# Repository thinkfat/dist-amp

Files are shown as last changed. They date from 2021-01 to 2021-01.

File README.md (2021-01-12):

dist-amp
========

This repository contains a 10MHz Distribution Amplifier (4  channels). It's
use is mainly in electronics labs or ham radio shacks for distributing a 
10MHz frequency standard (GPSDO, Rb atomic clock).

The circuit is based on a design by W. H. Rech, DF9IC, with minor modifications
by myself.

Documenation
------------

The *doc* folder contains the schematic in PDF format. It also contains S11/S21 measurements
done with a NanoVNA V2plus4 (nanovna-saver screenshot):

- Maximum input: 10dBm into 50 Ohm
- Cut-off frequency (-3dB): 13.8MHz
- Roll-off: 38dB/octave
- S11 @ 10MHz: -27dB
- S21 @ 10MHz: -0.7dB

Switching the ports I got also:
- S12 @ 10MHz: < -90dB

  In other words, the VNA cannot measure it. The dynamic range is not big enough.

Fabrication
-----------

The *fab* folder contains Gerber plots, a drill file and CPL+BOM files for
JLCPCB SMT service. If you want to recreate the board, remember to enable
impedance control and choose the JLC7628 PCB stack-up.

BOM
---

The *bom* folder contains an interactive HTML BOM you can open in a browser. It will
help with sourcing parts and assembling the PCB. Most parts are generic, but some parts
must meet either footprint or electrical constraints.

- L1, L2: Johanson Technology L-15F1R0JV4E
- U2: Maxim MAX4022ESD+
- J6: CUI PJ-037BH
- C13-C15: use MLCC capacitors with C0G/NP0 dielectric

Customization
-------------

The MAX4022ESD+ has a much larger bandwidth than the 12MHz imposed by the input filter.
One obvious modification is therefore to choose a higher roll-off frequency for the
input low-pass. Note that total bandwidth and flatness will also depend on parameters
of other components in the signal path, notably coupling capacitors at in and output.
These are currently generic 100nF MLCC with X7R dielectric. For more demanding applications,
you might need to find better ones.

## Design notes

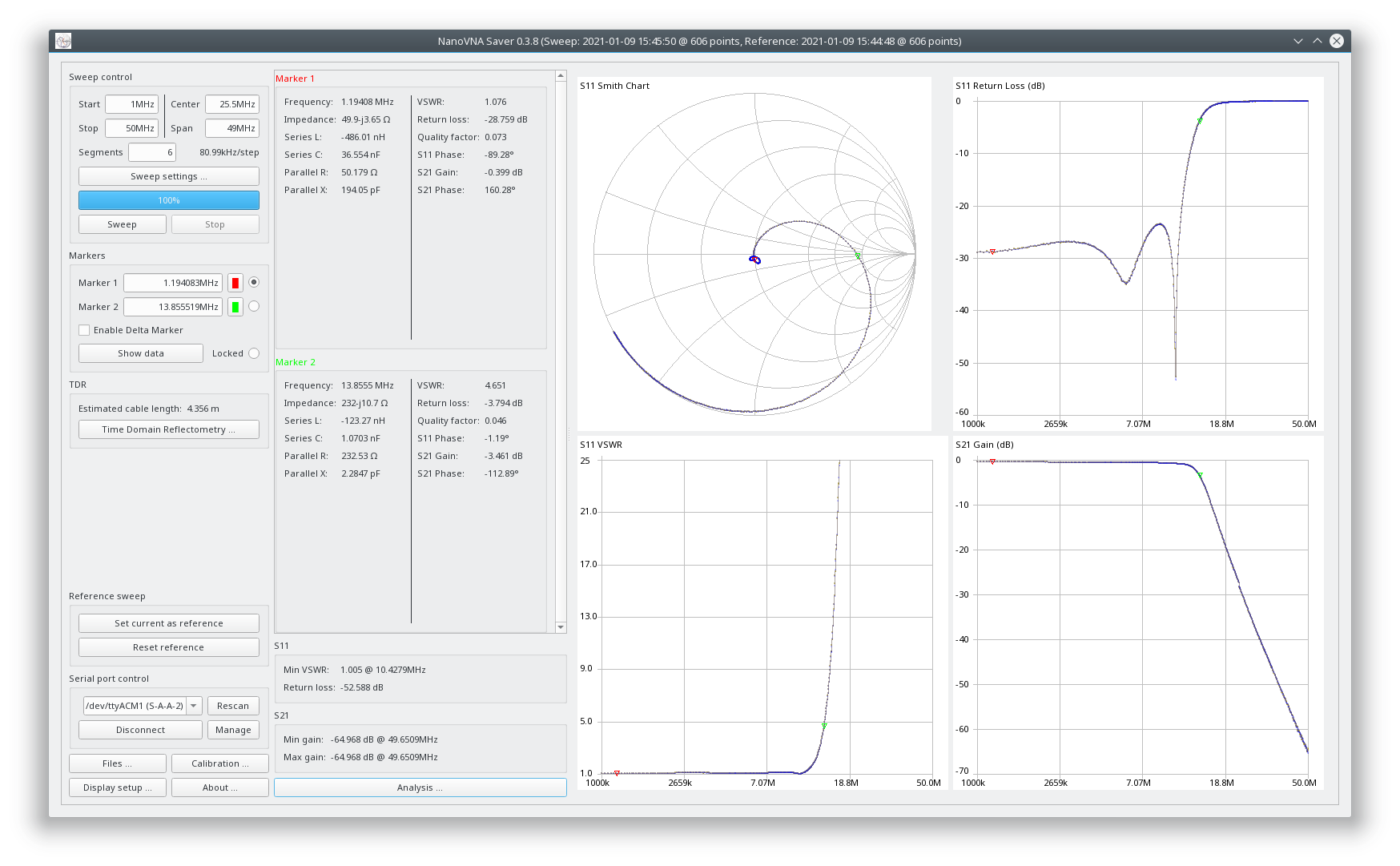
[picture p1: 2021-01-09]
doc/analysis.png

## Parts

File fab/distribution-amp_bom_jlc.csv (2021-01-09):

Comment | Designator | Footprint | LCSC Part #
10u | C8,C2,C3 | CP_Elec_5x5.4 | C72487
100n | C11,C6,C7,C10,C16,C4,C1,C9,C12,C5 | C_0805_2012Metric_Pad1.18x1.45mm_HandSolder | C49678
220p | C13,C15 | C_0805_2012Metric_Pad1.18x1.45mm_HandSolder | C61747
470p | C14 | C_0805_2012Metric_Pad1.18x1.45mm_HandSolder | C28256
1N4148WS | D1 | D_SOD-323 | C2128
49.9 | R1,R3,R5,R9,R7,R6 | R_0805_2012Metric_Pad1.20x1.40mm_HandSolder | C17720
10k | R4,R2 | R_0805_2012Metric_Pad1.20x1.40mm_HandSolder | C17414
4k7 | R8 | R_0805_2012Metric_Pad1.20x1.40mm_HandSolder | C17673
MC78M09_TO252 | U1 | TO-252-2 | C148310

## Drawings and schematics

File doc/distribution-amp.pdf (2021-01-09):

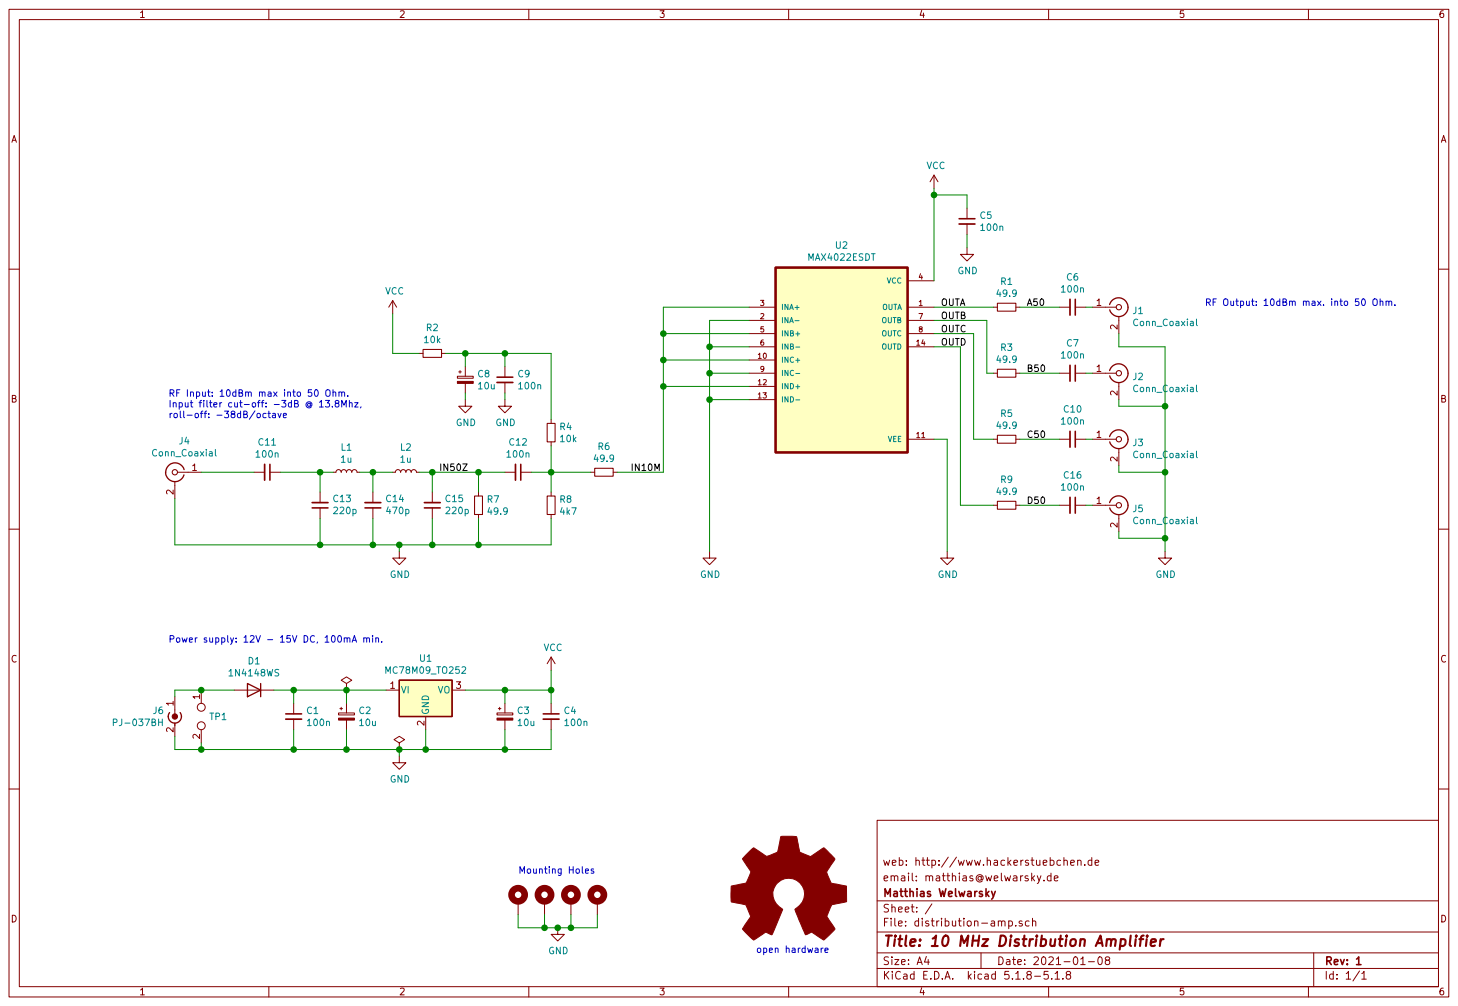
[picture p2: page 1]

INB- 6

INC- 9

RF Input: 10dBm max into 50 Ohm.

web: http://www.hackerstuebchen.de R4

IN50Z Power supply: 12V - 15V DC, 100mA min.

email: matthias@welwarsky.de
File: distribution-amp.sch Sheet: / Matthias Welwarsky

Id: 1/1 Title: 10 MHz Distribution Amplifier

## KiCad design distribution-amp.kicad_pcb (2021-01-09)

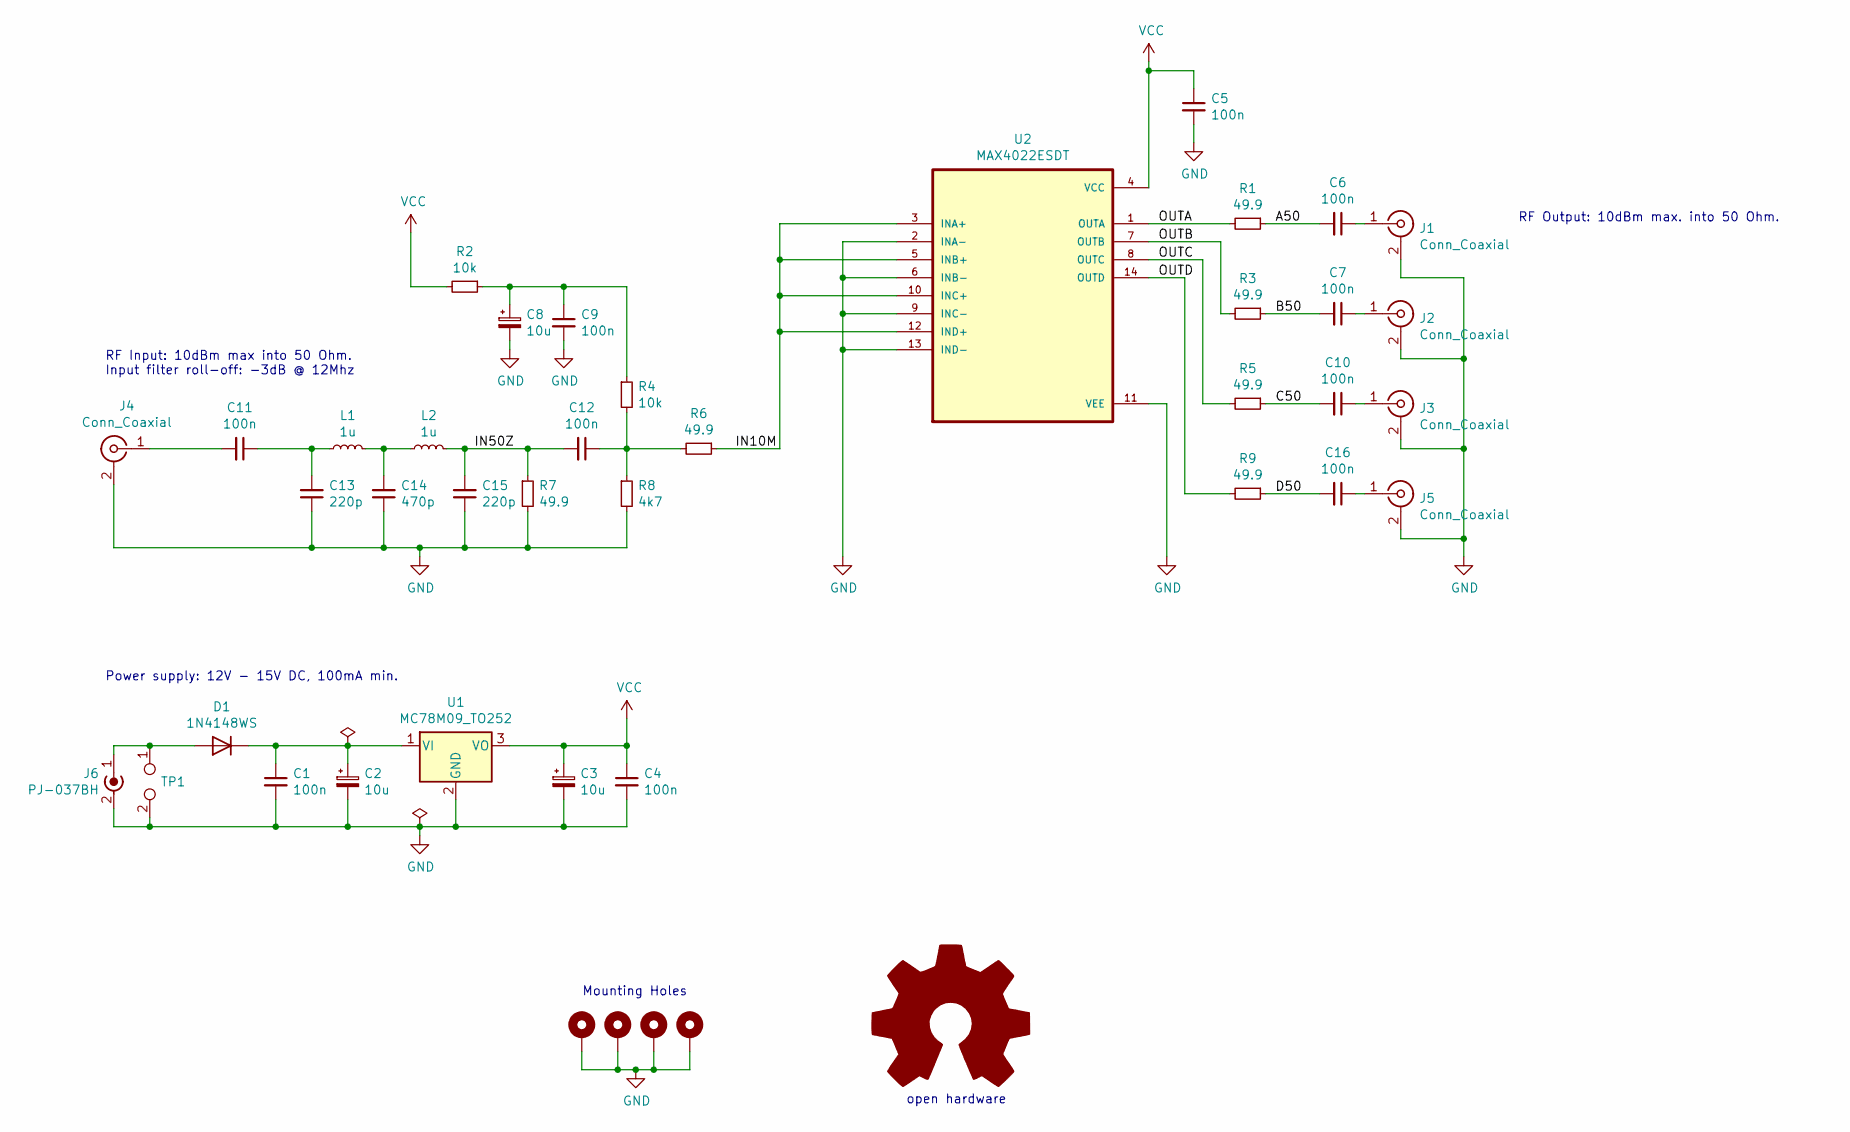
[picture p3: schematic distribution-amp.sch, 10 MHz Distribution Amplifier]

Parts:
C1, C4, C5, C6, C7, C9, C10, C11, C12, C16: 100n; C_0805_2012Metric_Pad1.18x1.45mm_HandSolder; LCSCPN C49678
C2, C3, C8: 10u; CP_Elec_5x5.4; LCSCPN C72487
C13, C15: 220p; C_0805_2012Metric_Pad1.18x1.45mm_HandSolder; LCSCPN C61747
C14: 470p; C_0805_2012Metric_Pad1.18x1.45mm_HandSolder; LCSCPN C28256
D1: 1N4148WS; D_SOD-323; LCSCPN C2128
H1, H2, H3, H4: MountingHole_Pad; MountingHole_3.2mm_M3_Pad_Via
J1, J2, J3, J4, J5: Conn_Coaxial; SMA_Amphenol_132203-12_Horizontal
J6: PJ-037BH; CUI_PJ-037BH
L1, L2: 1u; L_0805_2012Metric_Pad1.05x1.20mm_HandSolder
OSHW1: Logo_Open_Hardware_Large; OSHW-Logo2_14.6x12mm_Copper
R1, R3, R5, R6, R7, R9: 49.9; R_0805_2012Metric_Pad1.20x1.40mm_HandSolder; LCSCPN C17720
R2, R4: 10k; R_0805_2012Metric_Pad1.20x1.40mm_HandSolder; LCSCPN C17414
R8: 4k7; R_0805_2012Metric_Pad1.20x1.40mm_HandSolder; LCSCPN C17673
TP1: TestPoint_2Pole; PinHeader_1x02_P2.54mm_Vertical
U1: MC78M09_TO252; TO-252-2; LCSCPN C148310
U2: MAX4022ESDT; SOIC-14_3.9x8.7mm_P1.27mm

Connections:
/A50: C6.2, R1.1
/B50: C7.2, R3.1
/C50: C10.2, R5.1
/D50: C16.2, R9.1
/IN10M: R6.1, U2.3 (INA+), U2.5 (INB+), U2.10 (INC+), U2.12 (IND+)
/IN50Z: C12.2, C15.2, L2.2, R7.1
/OUTA: R1.2, U2.1 (OUTA)
/OUTB: R3.2, U2.7 (OUTB)
/OUTC: R5.2, U2.8 (OUTC)
/OUTD: R9.2, U2.14 (OUTD)
GND: C1.2, C2.2, C3.2, C4.2, C5.2, C8.2, C9.2, C13.1, C14.1, C15.1, H1.1, H2.1, H3.1, H4.1, J1.2 (Ext), J2.2 (Ext), J3.2 (Ext), J4.2 (Ext), J5.2 (Ext), J6.2 (Ext), R7.2, R8.2, TP1.2, U1.2 (GND), U2.2 (INA-), U2.6 (INB-), U2.9 (INC-), U2.11 (VEE), U2.13 (IND-)
unnamed: C1.1, C2.1, D1.1 (K), U1.1 (VI)
unnamed: C6.1, J1.1 (In)
unnamed: C7.1, J2.1 (In)
unnamed: C8.1, C9.1, R2.1, R4.1
unnamed: C10.1, J3.1 (In)
unnamed: C11.1, C13.2, L1.1
unnamed: C11.2, J4.1 (In)
unnamed: C12.1, R4.2, R6.2, R8.1
unnamed: C14.2, L1.2, L2.1
unnamed: C16.1, J5.1 (In)
unnamed: D1.2 (A), J6.1 (In), TP1.1
VCC: C3.1, C4.1, C5.1, R2.2, U1.3 (VO), U2.4 (VCC)

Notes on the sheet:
open hardware
Mounting Holes
Power supply: 12V - 15V DC, 100mA min.
RF Input: 10dBm max into 50 Ohm. Input filter roll-off: -3dB @ 12Mhz
RF Output: 10dBm max. into 50 Ohm.

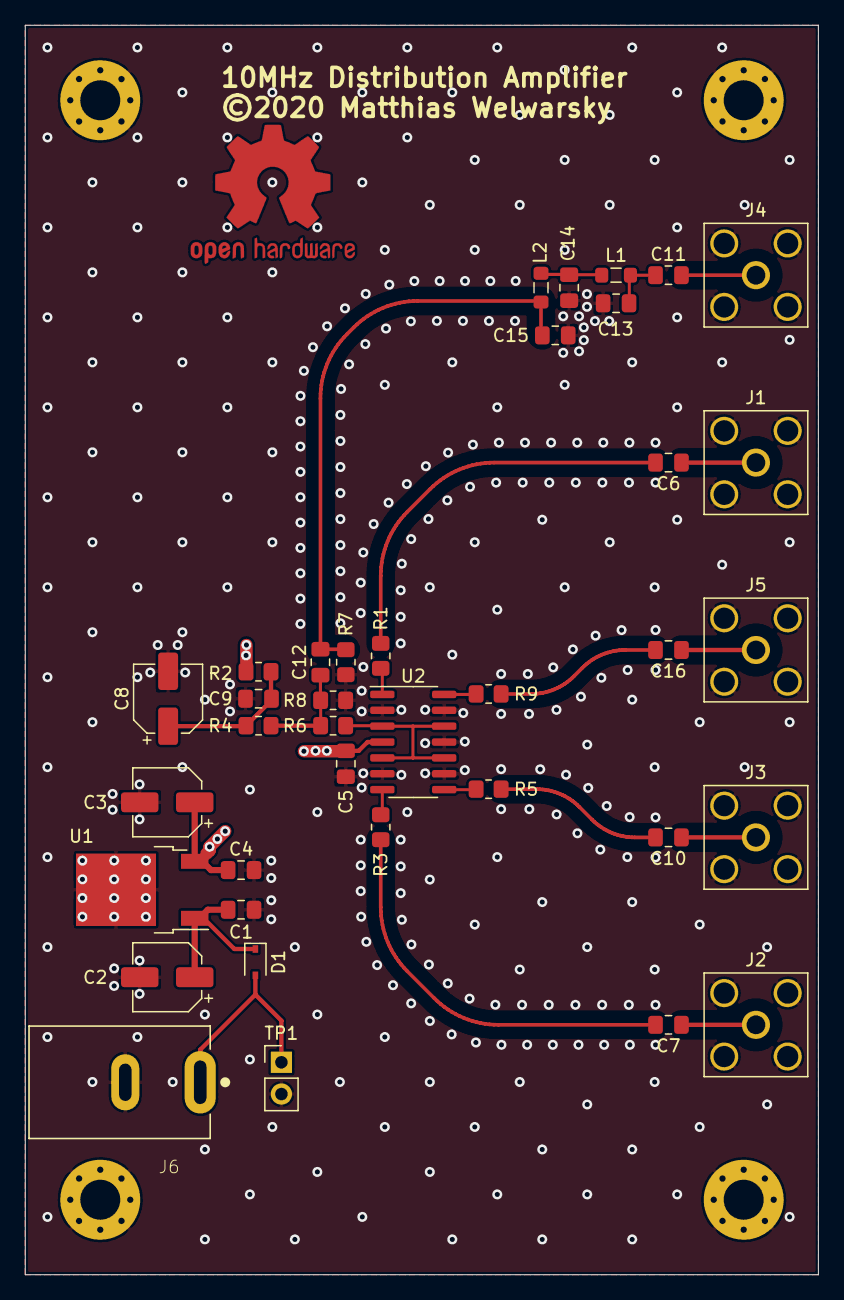
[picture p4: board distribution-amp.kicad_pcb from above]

Board: 4 copper layers, 63.5 x 100.0 mm, 42 parts (0 on the bottom side), 23 nets.

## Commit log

2021-01-09 Add documentation
    [distribution-amp.kicad_pcb, distribution-amp.sch]
2021-01-09 Documentation update
    [distribution-amp.sch]

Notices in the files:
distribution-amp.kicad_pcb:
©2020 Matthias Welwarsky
